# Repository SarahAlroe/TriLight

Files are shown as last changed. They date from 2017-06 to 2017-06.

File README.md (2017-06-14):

# Trilight  
_NeoPixel based lamp with dynamic colour temperature_

TriLight is a lamp which dynamically adjuss its colour temperature based on the time of day. By reducing the amount of blue light in the evening and night, melatonin suppression is avoided, which allows for better sleep at night.  
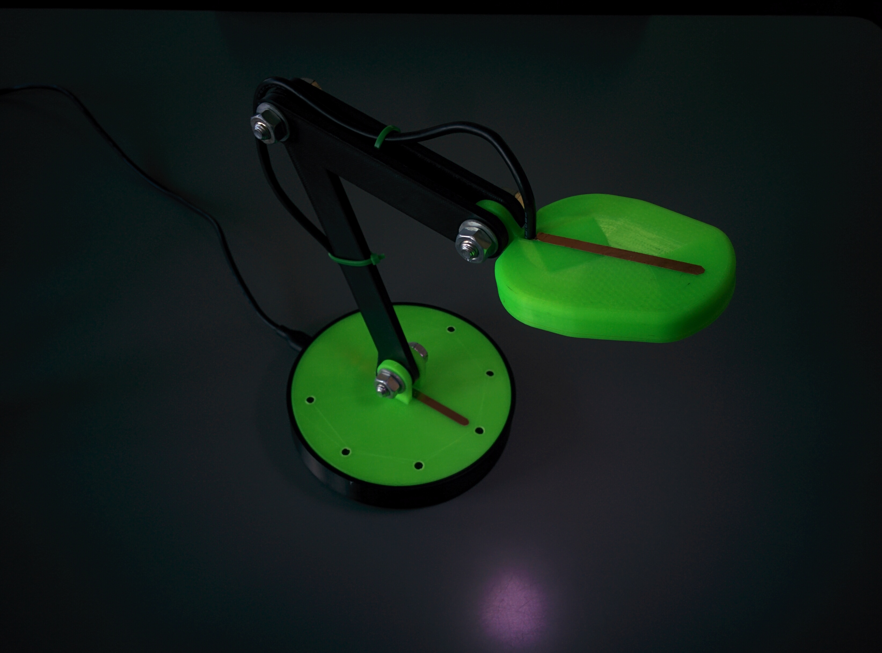
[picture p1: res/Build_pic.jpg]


## BOM

Electrics and electronics:
+ 1x Arduino nano
+ 1x DS3238 RTC Module
+ 14x DS2812 (NeoPixel)
+ 15cm Copper tape
+ 30cm 4 wire cable (Ex. USB 2.0 cable)
+ A bit of solidcore wire (or multicore if you hate yourself)

Lamp:
+ 3 8mm nuts
+ 3 8mm bolts
+ 12 8mm washers

Tools:
+ 3D printer
+ Soldering iron

## Things to print
+ 1x Base - Bottom
+ 1x Base - Top
+ 1x Arm  - 1
+ 2x Arm  - 2
+ 1x Head - Bottom  (v2)
+ 1x Head - Top     (v2)
Files can be found in /STL, or /Inventor if you wish to modify it.

## Circuit
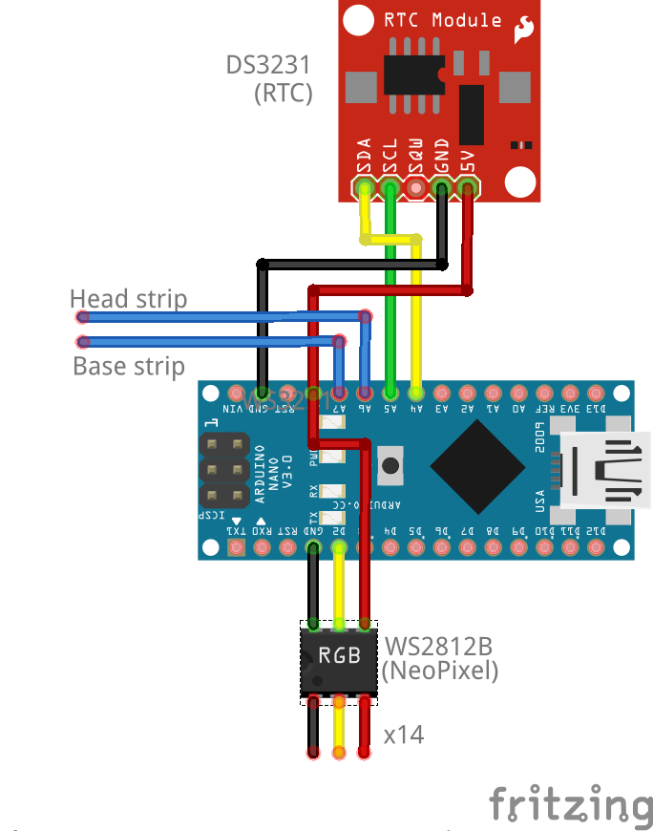
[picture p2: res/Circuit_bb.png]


## Steps
1. Assemble lamp with washers between each plastic part
1. Solder DS2812's together (easier if not broken apart)
1. Mount tape and cable on lamp, solder together
1. Solder remaining parts and mount with hot glue
1. Add weights to base
1. Assemble lamp base (holes might need drilling)
1. Download Aduino software, install libraries and flash
1. Run configuration utility

## Dependencies
+ DS3231 - For interacting with RTC module
+ ADCTouch - For doing touch sensing
+ Adafruit_NeoPixel - For obvious reasons

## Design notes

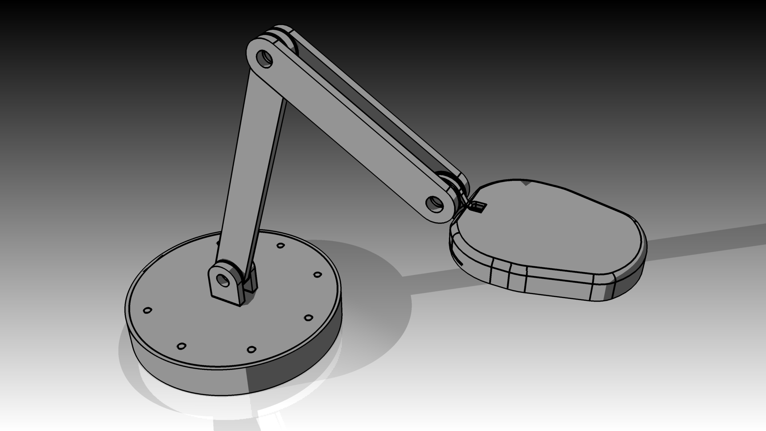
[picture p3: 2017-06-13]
res/Lamp_linetrace_v2.png

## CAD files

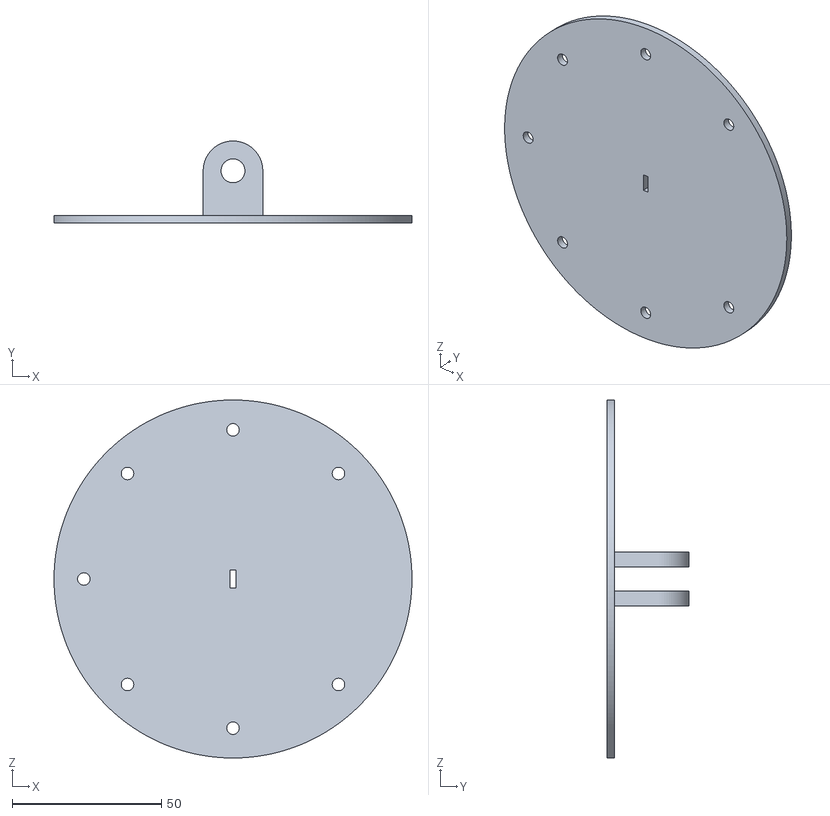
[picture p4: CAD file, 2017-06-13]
STL/Base - Top.stl
120.0 x 27.5 x 120.0

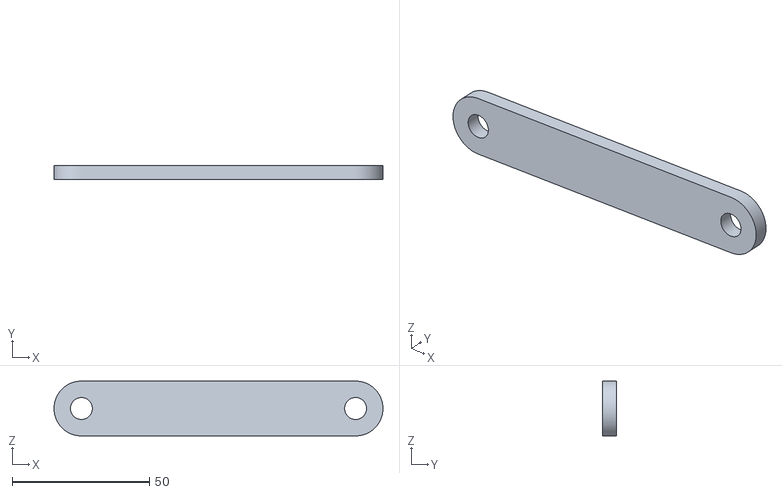
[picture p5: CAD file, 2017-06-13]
STL/Arm - 2.stl
120.0 x 5.00 x 20.0

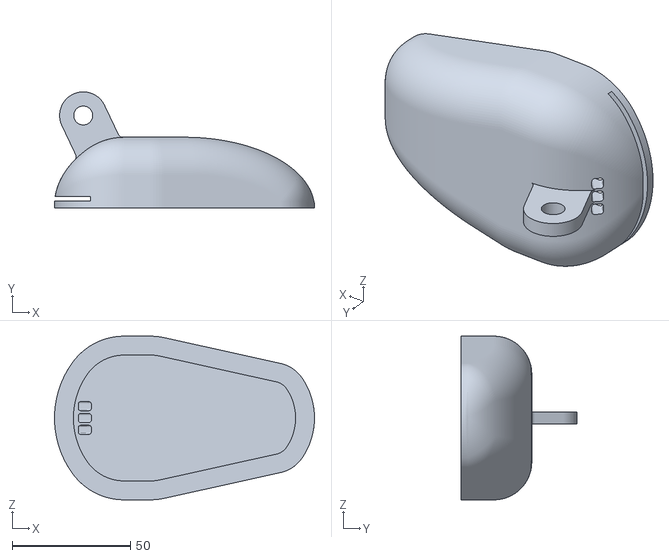
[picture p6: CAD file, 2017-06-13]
STL/Head.stl
110.0 x 49.2 x 69.2

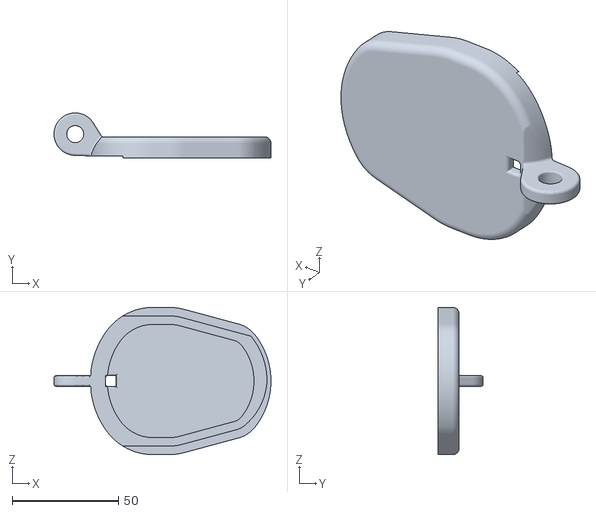
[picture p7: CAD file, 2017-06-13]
STL/Head - Top v2.stl
102.1 x 21.3 x 69.2

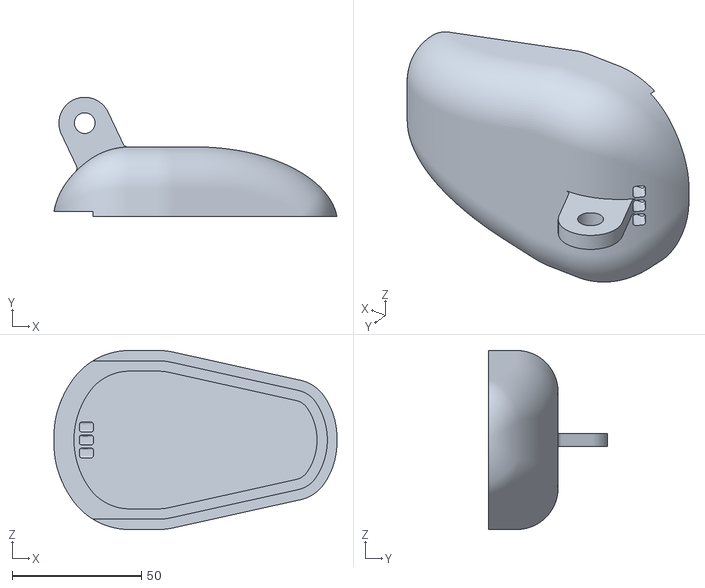
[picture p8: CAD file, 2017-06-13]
STL/Head - Top.stl
109.5 x 46.2 x 69.2

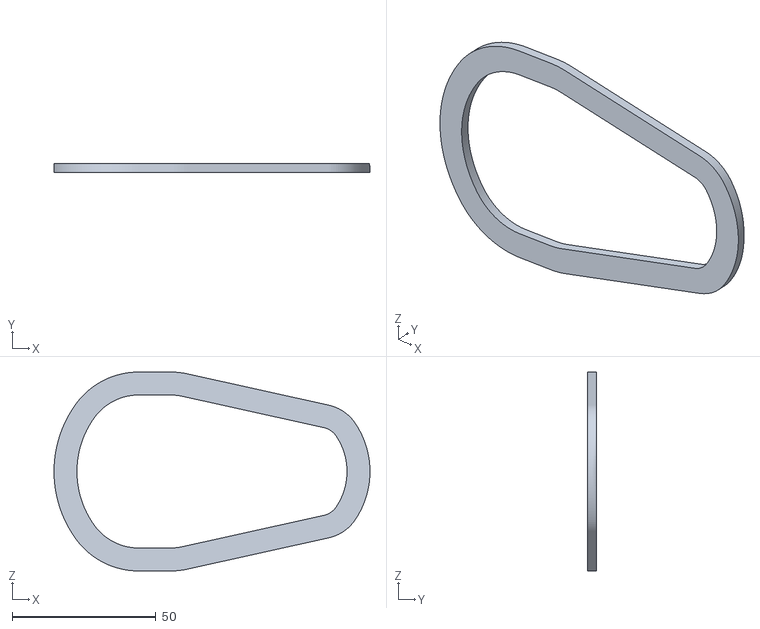
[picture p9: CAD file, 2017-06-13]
STL/Head - Bottom.stl
110.0 x 3.00 x 69.2

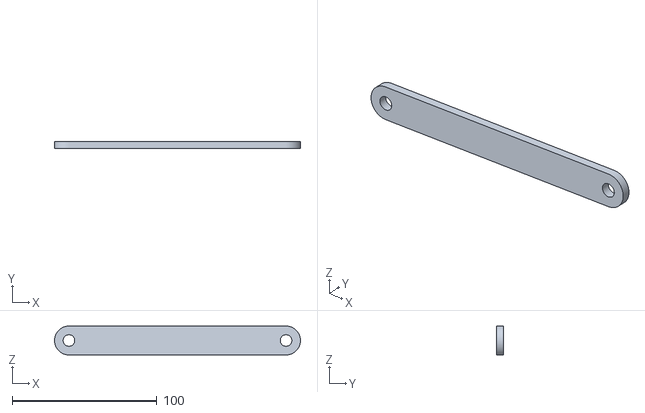
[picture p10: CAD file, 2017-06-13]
STL/Arm - 1.stl
170.0 x 5.00 x 20.0

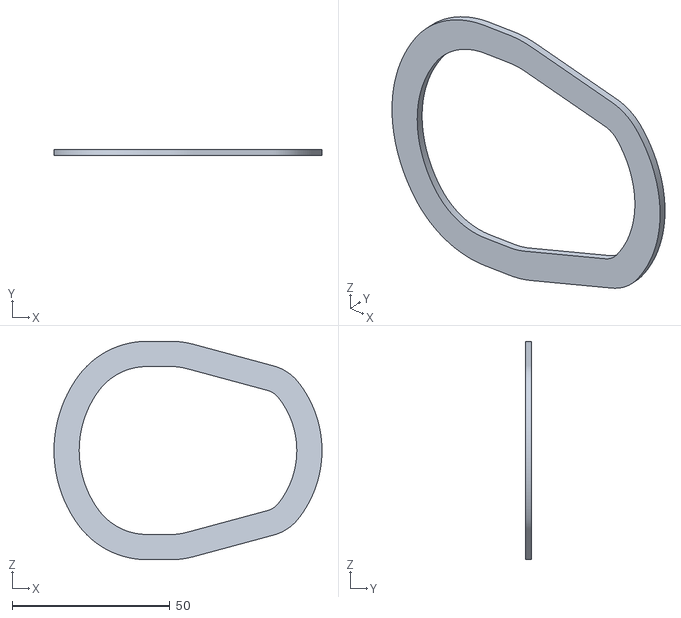
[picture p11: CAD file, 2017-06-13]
STL/Head - Bottom v2.stl
85.0 x 2.00 x 69.2

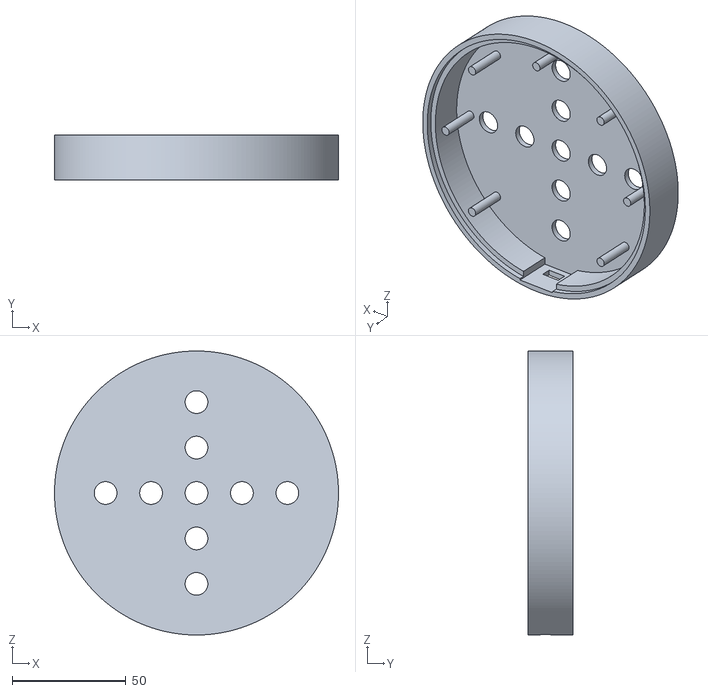
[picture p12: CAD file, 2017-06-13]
STL/Base - Bottom.stl
125.0 x 20.0 x 125.0

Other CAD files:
Inventor/Arm - 1.ipt
Inventor/Arm - 2.ipt
Inventor/Base - Bottom.ipt
Inventor/Base - Top.ipt
Inventor/Head v2.ipt
Inventor/Head.ipt
Inventor/Lamp.iam
Inventor/Rondelle.ipt

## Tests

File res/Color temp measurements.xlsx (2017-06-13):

Rød er altid 255
Grøn beregnes ved mapping med bølgelængder
Blå går fra max (255) til en teoretisk -135. hvor g=0
r | g | b | temp 1 | temp 2 | temp 3 | temp 4 | temp 5 | avg temp
255 | 255 | 255 | 11060 | 11170 | 11090 | 11480 | 11360 | 11232
255 | 252 | 250 | 9990 | 10190 | 10280 | 10320 | 10330 | 10222
255 | 249 | 245 | 10420 | 10460 | 10460 | 10480 | 10490 | 10462
255 | 246 | 240 | 10200 | 10200 | 10230 | 10210 | 10220 | 10212
255 | 242 | 235 | 10040 | 10170 | 10200 | 10200 | 10220 | 10166
255 | 239 | 230 | 9970 | 9950 | 9970 | 9950 | 9960 | 9960
255 | 236 | 225 | 10020 | 10040 | 9810 | 9810 | 9820 | 9900
255 | 232 | 220 | 9690 | 9710 | 9710 | 9710 | 9710 | 9706
255 | 229 | 215 | 9760 | 9730 | 9740 | 9750 | 9740 | 9744
255 | 226 | 210 | 9620 | 9600 | 9610 | 9620 | 9610 | 9612
255 | 223 | 205 | 9490 | 9490 | 9490 | 9490 | 9500 | 9492
255 | 219 | 200 | 9330 | 9310 | 9320 | 9350 | 9330 | 9328
255 | 216 | 195 | 9190 | 9170 | 9170 | 9210 | 9230 | 9194
255 | 213 | 190 | 9100 | 9090 | 9140 | 9140 | 9040 | 9102
255 | 209 | 185 | 9000 | 9000 | 9010 | 9050 | 9000 | 9012
255 | 206 | 180 | 8900 | 8910 | 8790 | 8830 | 8830 | 8852
255 | 203 | 175 | 8740 | 8780 | 8750 | 8800 | 8740 | 8762
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

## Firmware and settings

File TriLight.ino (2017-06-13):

//TriLight lamp control
//By Silas Alrøe

//Include used libraries
#include <EEPROM.h>             //Allows storage of lamp data in non-volatile memory
#include <DS3231.h>             //Allows interaction with RTC module without directly using i2c
#include <Wire.h>               //Used by DS3231 for i2c communication with RTC
#include <ADCTouch.h>           //Lets analog pins be used as touch sensors by using internal capacitors intelligently
#include <Adafruit_NeoPixel.h>  //Allows control of WS2812 RGB LEDs and other Neopixel products

//Neopixel values
#define NEOPIN 2      //Pin on which pixels are connected
#define NUMPIXELS 14  //Number of pixels on string
#define ANIMINC 0.01  //Amount to change intensity by when animating

//Touch config values
#define THEAD A6          //Pin for the head touch button
#define TBASE A7          //Pin for the base touch button
#define TINITSAMPLES 500  //Amount of samples for touch reference measurement
#define TSENSESAMPLES 100 //Amount of continious samples when checking for touch
#define TACTIVATE 70      //Sensitivity of touch buttons - higher value means lower sensitivity

//LED wavelengths as according to WS2812 spec sheet
#define rwl 625 //Red
#define gwl 523 //Green
#define bwl 470 //Blue

//Temperature to blue light conversion values
#define TEMPA 0.03527021888377 //Multiplier
#define TEMPB -109.285         //Addition

//Interval for large tasks
#define TMINT 25 //Amount of cycles

//Initialize neopixels and RTC libraries
Adafruit_NeoPixel pixels = Adafruit_NeoPixel(NUMPIXELS, NEOPIN, NEO_GRB + NEO_KHZ800);
DS3231 Clock;

//Map pixels from center for nicer dithering
const int pixelMap[] = {5, 6, 9, 10, 4, 7, 1, 2, 0, 3, 12, 13, 8, 11}; //Starts at middle, moving outwards in semi-spiral

bool h12;
bool PM;

//Init global values
int refHead, refBase;               //Touch reference values
int powerState = 1;                 //Turned on or off 0/1
float intensity = 0.25;             //Target intensity of pixels - starts at 0.25
int targetTemperatureLow = 100;     //Target temperature at night - is replaced with values from EEPROM
int targetTemperatureHigh = 10000;  //Target temperature at day - is replaced with values from EEPROM
int currentTemperature = 1000;      //Temperature at current time - is overwritten continiously
bool touchIsPressed, headIsTouched, touchWasPressed, headWasTouched, scrollingUp; //Program state bools
bool redMode = false;               //Is red night-light enabled
bool demoMode = false;              //Is demoMode enabled
int demoModeCounter = 0;            //Counter for handling demoMode logic

float movIntensity = 0.0;           //Actual intensity of the pixels
float prevIntensity = intensity;    //Target intensity before lamp was turned off

int tmc = 0; //Program cycle counter
int hour, minute, second, sDHour, sDMinute, sRHour, sRMinute, intHour, intMinute; //Time used for calculating intensity

void setup() {
  //Init serial
  Serial.begin(9600);
  //Init pixels
  pixels.begin();
  //Init touch
  refHead = ADCTouch.read(THEAD, TINITSAMPLES);
  refBase = ADCTouch.read(TBASE, TINITSAMPLES);
  //Init RTC
  Wire.begin();
  //Load stored values for temperature transition
  loadVals();
  //Calculate the current temperature to avoid jagging colorchange
  calculateTemperature();
}

void loop() {
  //Read serial for possible update to data
  readSerial();
  //Check touch buttons
  handleTouch();
  //Update pixels
  setFromTemperature(currentTemperature, intensity);
  //Only do this every TMINT cycle
  if (tmc >= TMINT) {
    //Calculate the temperature of light
    calculateTemperature();
    tmc = 0;
  }
  tmc ++;
  //DEMOMODE - Should be removed in final product
  handleDemoMode();
}

//SERIAL
void readSerial() {
  //Format: HH MM SdhSdh SdmSdm SrhSrh SrmSrm IhIh ImIm [Target temp low] [Target temp high]
  //EX: 23x58x22x30x06x30x01x02x500x8000
  //If serial has data available
  while (Serial.available() > 0) {
    //Read current time
    char hour = char(Serial.parseInt());
    char minute = char(Serial.parseInt());

    //Read sundown time
    sDHour = Serial.parseInt();
    sDMinute = Serial.parseInt();

    //Read sunrise time
    sRHour = Serial.parseInt();
    sRMinute = Serial.parseInt();

    //Read transition time
    intHour = Serial.parseInt();
    intMinute = Serial.parseInt();

    //Read maximum and minimum temperature
    int temperatureL = Serial.parseInt();
    int temperatureH = Serial.parseInt();

    //If the datastream has finished with a newline
    if (Serial.read() == '\n') {
      //Set final temperature values
      targetTemperatureLow = temperatureL;
      targetTemperatureHigh = temperatureH;

      //Update the RTC with new time in 24h format
      Clock.setClockMode(false);
      Clock.setHour(hour);
      Clock.setMinute(minute);
      //Return new time over serial
      Serial.print(Clock.getHour(h12, PM));
      Serial.print(":");
      Serial.print(Clock.getMinute());
      //Save new values to EEPROM
      saveVals();
    }
  }
  //OLD
  /*while (Serial.available() > 0) {
    // Read ints from serial
    int temperature = Serial.parseInt();
    intensity = 0.1;

    // Set on newline
    if (Serial.read() == '\n') {
      targetTemperature = temperature;
    }
    }*/
}

//SAVE / LOAD
void saveVals() {
  //Save values sDH, sdM sRH, sRM Ih Im Tl Th to EEPROM
  //Start at EEPROM position 0
  int ePos = 0;
  //Set variable
  EEPROM.put(ePos, sDHour);
  //Add size in bytes of the variable to the position
  ePos += sizeof(int);
  //Cont...
  EEPROM.put(ePos, sDMinute);
  ePos += sizeof(int);
  EEPROM.put(ePos, sRHour);
  ePos += sizeof(int);
  EEPROM.put(ePos, sRMinute);
  ePos += sizeof(int);
  EEPROM.put(ePos, intHour);
  ePos += sizeof(int);
  EEPROM.put(ePos, intMinute);
  ePos += sizeof(int);
  EEPROM.put(ePos, targetTemperatureLow);
  ePos += sizeof(int);
  EEPROM.put(ePos, targetTemperatureHigh);
  ePos += sizeof(int);

}

void loadVals() {
  //Load values sDH, sdM sRH, sRM Ih Im Tl Th from EEPROM
  //Start at EEPROM position 0
  int ePos = 0;
  //Get variable
  EEPROM.get(ePos, sDHour);
  //Add size in bytes of the variable to the position
  ePos += sizeof(int);
  //Cont...
  EEPROM.get(ePos, sDMinute);
  ePos += sizeof(int);
  EEPROM.get(ePos, sRHour);
  ePos += sizeof(int);
  EEPROM.get(ePos, sRMinute);
  ePos += sizeof(int);
  EEPROM.get(ePos, intHour);
  ePos += sizeof(int);
  EEPROM.get(ePos, intMinute);
  ePos += sizeof(int);
  EEPROM.get(ePos, targetTemperatureLow);
  ePos += sizeof(int);
  EEPROM.get(ePos, targetTemperatureHigh);
  ePos += sizeof(int);
}

//TIME
void calculateTemperature() {
  //RED mode clause
  if (redMode) {
    //Just set temperature very low and return
    currentTemperature = 100;
    return;
  }

  //Get time from RTC and get total minutes since 00:00
  int hour = int(Clock.getHour(h12, PM));
  int minute = int(Clock.getMinute());
  int totalTime = hour * 60 + minute;

  //Calculate same for sundown, sunrise and interval
  int sDPoint = sDHour * 60 + sDMinute;
  int sRPoint = sRHour * 60 + sRMinute;
  int intSpan = intHour * 60 + intMinute;
  //Halve interval to place sunrise and sundown times in middle of transition
  int hIntSpan = intSpan / 2;

  //Assuming sDPoint is before 0
  //If time is after sunrise transition and before sundown transition, set temperature to maximum
  if (totalTime > (sRPoint + hIntSpan) && totalTime < (sDPoint - hIntSpan)) {
    currentTemperature = targetTemperatureHigh;
    //Else if time is after sundown transition and before sunrise transition, set temperature to minimum
  } else if (totalTime < (sRPoint - hIntSpan) || totalTime > (sDPoint + hIntSpan)) {
    currentTemperature = targetTemperatureLow;
    //Else if time is during sunrise transition, map temperature linearly from min to max through transition time
  } else if (totalTime > (sRPoint - hIntSpan) && totalTime < (sRPoint + hIntSpan)) {
    currentTemperature = map(totalTime, sRPoint - hIntSpan, sRPoint + hIntSpan, targetTemperatureLow, targetTemperatureHigh);
    //Else if time is during sundown transition, map temperature linearly from max to min through transition time
  } else if (totalTime > (sDPoint - hIntSpan) && totalTime < (sDPoint + hIntSpan)) {
    currentTemperature = map(totalTime, sDPoint - hIntSpan, sDPoint + hIntSpan, targetTemperatureHigh, targetTemperatureLow);
  }

}

//TOUCH
void handleTouch() {
  //Sets powerState on unique touch
  if (isTouched()) {
    //Usual cycle: Off -> (red, on) -> On -> off
    //If the lamp is off, turn it on
    if (powerState == 0) {
      //Reset to ligt intensity before lamp was turned off
      intensity = prevIntensity;
      powerState = 1;
      //If it's dark outside, start in redmode
      if (isDark()) {
        redMode = true;
        //Recalculate temperature to get redMode temperature
        calculateTemperature();
      }
    } else if (redMode) {
      //Else if lamp is on and in redMode, disable it and update
      redMode = false;
      calculateTemperature();
    } else {
      //Else if lamp is just on, turn it off, and store the previous light intensity
      powerState = 0;
      prevIntensity = intensity;
      intensity = 0.0;
    }
  }
  //Serial.print(powerState);
  //Check if light intensity button is touched and act accordingly
  checkIntensityScroll();
}

bool isDark() {
  //Check if it's dark by checking if time is after sundown
  int hour = int(Clock.getHour(h12, PM));
  int minute = int(Clock.getMinute());
  int totalTime = hour * 60 + minute;

  int sDPoint = sDHour * 60 + sDMinute;
  int sRPoint = sRHour * 60 + sRMinute;
  int intSpan = intHour * 60 + intMinute;
  int hIntSpan = intSpan / 2;

  //Assuming sDPoint is before 0
  if (totalTime < (sRPoint - hIntSpan) || totalTime > (sDPoint + hIntSpan)) {
    return true;
  }
  return false;
}

bool isTouched() {
  //Check if touch is unique by seeing if was touched in previous cycle
  bool ret = false;
  touchIsPressed = touchPressed();
  if (touchIsPressed && !touchWasPressed) {
    ret = true;
    touchWasPressed = true;
  } else if (!touchIsPressed) {
    touchWasPressed = false;
  }
  return ret;
}

bool touchPressed() {
  //Return true if head touch button is pressed
  if ((ADCTouch.read(THEAD, TSENSESAMPLES) - refHead) > TACTIVATE) {
    return true;
  }
  return false;
}

void checkIntensityScroll() {
  if (powerState == 1) {
    //Check base button to scroll intensity up or down
    headIsTouched = ((ADCTouch.read(TBASE, TSENSESAMPLES) - refBase) > TACTIVATE);
    if (headIsTouched) {
      //Check if this is a new touch - if so, reverse the scroll direction
      if (!headWasTouched) {
        scrollingUp = !scrollingUp;
      }
      //Add or subtract ANIMINC amount to pixel intensity if scrolling up or down
      if (scrollingUp) {
        intensity += ANIMINC; //Use own constant?
      } else {
        intensity -= ANIMINC;//Use own constant?
      }
      //Constrain intensity to be within logical limits
      if (intensity < 0.0) {
        intensity = 0.0;
      } else if (intensity > 1.0) {
        intensity = 1.0;
      }
      //Stop continious touch from counting as a new
      headWasTouched = true;
    } else {
      //Reset wasTouched to allow levels to be reversed again.
      headWasTouched = false;
    }
  }
}

//NEOPIXEL
void setFromTemperature(int temperature, float intensity) {
  //Move the actual intensity of the pixels (movIntensity) towards the target intensity (intensity)
  //This creates a smooth transition from one intensity to another
  //If the difference between intensity is larger than the animation change, change the actual intensity in that direction.
  if (intensity > movIntensity && (intensity - movIntensity) > ANIMINC) {
    movIntensity += ANIMINC;
  } else if (intensity < movIntensity && (movIntensity - intensity) > ANIMINC) {
    movIntensity -= ANIMINC;
    //Else if the change is smaller than the animation change, just set it directly to the intensity value.
    //This stops continious jittering between two values on each side of intensity
  } else if (intensity > movIntensity && (intensity - movIntensity) <= ANIMINC) {
    movIntensity = intensity;
  } else if (intensity < movIntensity && (movIntensity - intensity) <= ANIMINC) {
    movIntensity = intensity;
  }

  //Calculate the red green and blue base values
  float r = 255.0;
  //Blue is calculated with formula - see function
  float b = calcBlue(temperature);
  //Green is interpolated linearly from red to blue, using their primary wavelength as positions
  float g = map(gwl, rwl, bwl, r, b);
  //bool doUpdate = false; <-- Old stuff, ignore
  //if (doUpdate) {

  //Dither the pixels with base values times the actual intensity
  ditherPixels(r * movIntensity, g * movIntensity, b * movIntensity);
  //}
}

float calcBlue(int temperature) {
  //Using externally calculated constants, calculate the fitting amount of blue for a specific temperature
  return temperature * TEMPA + TEMPB;
}

//OLD + Unused
/*void setPixels(int r, int g, int b) {
  // constrain the values to 0 - 255
  r = constrain(r, 0, 255) * powerState;
  g = constrain(g, 0, 255) * powerState;
  b = constrain(b, 0, 255) * powerState;

  for (int pixnum = 0; pixnum < NUMPIXELS; pixnum++) {
    pixels.setPixelColor(pixnum, pixels.Color(r, g, b));
    pixels.show();
    //printPixels(r,g,b);
  }
  }*/

void ditherPixels(float r, float g, float b) {
  int sr, sg, sb;

  //Calculate floor and ceiling values of rgb
  int rHi = ceil(r);
  int rLo = floor(r);
  //Isolate decimal part of float and multiply for pixel count
  //This lets extra detail of float be represented in a fitting amount of pixels being slightly brighter
  int rPC = int((r * 10.0 - float(rLo * 10)) * 1.4);

  int gHi = ceil(g);
  int gLo = floor(g);
  int gPC = int((g * 10.0 - float(gLo * 10)) * 1.4);

  int bHi = ceil(b);
  int bLo = floor(b);
  int bPC = int((b * 10.0 - float(bLo * 10)) * 1.4);

  //Iterate through all pixels
  for (int pixnum = 0; pixnum < NUMPIXELS; pixnum++) {
    //if current pixel is within count of those brighter, set it to the ceil value, else floor
    if (pixnum < rPC) {
      sr = constrain(rHi, 0, 255);
    } else {
      sr = constrain(rLo, 0, 255);
    }

    if (pixnum < gPC) {
      sg = constrain(gHi, 0, 255);
    } else {
      sg = constrain(gLo, 0, 255);
    }

    if (pixnum < bPC) {
      sb = constrain(bHi, 0, 255);
    } else {
      sb = constrain(bLo, 0, 255);
    }
    //Set each pixel at their mapped position to the calculated color/brightness
    pixels.setPixelColor(pixelMap[pixnum], pixels.Color(sr, sg, sb));
    //printPixels(sr,sg,sb);
  }
  //Push new ligt settings to pixels
  pixels.show();
}

//EXTRA
//Prints pixel state - not currently in use
void printPixels(int r, int g, int b) {
  Serial.print(r);
  Serial.print(" ");
  Serial.print(g);
  Serial.print(" ");
  Serial.println(b);
}
void handleDemoMode() {
  //Enables demoing of the product
  if (touchIsPressed && headIsTouched) {
    demoMode = true;
    demoModeCounter = 0;
  }
  if (demoMode) {
    demoModeCounter += 1;
    //Copy-Pasted from time temperature keeper
    //RED mode clause
    if (redMode) {
      //Just set temperature very low and return
      currentTemperature = 100;
      return;
    }
    int totalTime = demoModeCounter; //Time is now counter

    //Calculate same for sundown, sunrise and interval
    int sDPoint = sDHour * 60 + sDMinute;
    int sRPoint = sRHour * 60 + sRMinute;
    int intSpan = intHour * 60 + intMinute;
    //Halve interval to place sunrise and sundown times in middle of transition
    int hIntSpan = intSpan / 2;

    //Assuming sDPoint is before 0
    //If time is after sunrise transition and before sundown transition, set temperature to maximum
    if (totalTime > (sRPoint + hIntSpan) && totalTime < (sDPoint - hIntSpan)) {
      currentTemperature = targetTemperatureHigh;
      //Else if time is after sundown transition and before sunrise transition, set temperature to minimum
    } else if (totalTime < (sRPoint - hIntSpan) || totalTime > (sDPoint + hIntSpan)) {
      currentTemperature = targetTemperatureLow;
      //Else if time is during sunrise transition, map temperature linearly from min to max through transition time
    } else if (totalTime > (sRPoint - hIntSpan) && totalTime < (sRPoint + hIntSpan)) {
      currentTemperature = map(totalTime, sRPoint - hIntSpan, sRPoint + hIntSpan, targetTemperatureLow, targetTemperatureHigh);
      //Else if time is during sundown transition, map temperature linearly from max to min through transition time
    } else if (totalTime > (sDPoint - hIntSpan) && totalTime < (sDPoint + hIntSpan)) {
      currentTemperature = map(totalTime, sDPoint - hIntSpan, sDPoint + hIntSpan, targetTemperatureHigh, targetTemperatureLow);
    }
  }

  if (demoModeCounter >= 1440) { //Full day
    demoMode = false;
  }
}

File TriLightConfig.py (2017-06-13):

#Trilight configuration utility
#By Silas Alrøe
#REQUIRES pySerial! (And a linux pc...)
import serial           #Used for communication with arduino
import datetime         #Gets current time from system so user does not have to input it
import subprocess as sp #Used for clearing terminal screen for neatness

tmp = sp.call('clear',shell=True)   #Clear terminal

ser = serial.Serial('/dev/ttyUSB0', 9600)   #Initialize serial connection to lamp
print( "  _______   _ _      _       _     _   ")   #Print ascii graphic
print( " |__   __| (_) |    (_)     | |   | |  ")   #Just because it looks nice
print( "    | |_ __ _| |     _  __ _| |__ | |_ ")
print( "    | | '__| | |    | |/ _\`| '_ \| __|")
print( "    | | |  | | |____| | (_| | | | | |_ ")
print( "    |_|_|  |_|______|_|\__, |_| |_|\__|")
print( "                        __/ |          ")
print( "                       |___/           ")
print("")

print ("Welcome to the TriLight configuration utility") #Print welcome
print ("")
print("Please input the time in the evening you want to start relaxing")    #Request sundown time in hh/mm
sDH = raw_input("Hour: ")   #Input_raw displays text and returns following user-inputted line from terminal
sDM = raw_input("Minute: ")
print ("")

print("Please input the time you get up")   #Request sunrise time in hh/mm
sRH = raw_input("Hour: ")
sRM = raw_input("Minute: ")
print ("")

print("Please input the time to transition the light")  #Request transition time in hh/mm
iH = raw_input("Hour: ")
iM = raw_input("Minute: ")
print ("")

print("Please input the day and night temperature (100 - 10 000)")  #Request min and max temperature to cycle between
tH = raw_input("Day: ")
tL = raw_input("Night: ")
print ("")

print("Thank you, setting time and configuration")  #Print thank you

now = datetime.datetime.now() #Get current date/time

sendString = str(now.hour)+"x"+str(now.minute)+"x"+sDH+"x"+sDM+"x"+sRH+"x"+sRM+"x"+iH+"x"+iM+"x"+tL+"x"+tH  #Composite string fo sending
print("Sending: "+sendString)   #Print pending action to user
ser.write(sendString+"\n")      #Send string to arduino

print("Response: "+str(ser.readline())) #Print response from arduino to user to check success
